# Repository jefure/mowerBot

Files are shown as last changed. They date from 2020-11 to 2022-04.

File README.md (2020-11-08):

# mowerBot
Code for a lawn mowing robot using python on a raspberry py and an arduino

References:
https://howtomechatronics.com/tutorials/arduino/arduino-dc-motor-control-tutorial-l298n-pwm-h-bridge/

Simular Projects:
https://www.ardumower.de/en/
https://github.com/sm6yvr/liam
https://github.com/trycoon/liam-esp

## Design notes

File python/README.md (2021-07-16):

# Raspberry Pi code for controlling the mower bot.

In this folder you'll find the code that should be installed on the raspberry pi to controll the bot.

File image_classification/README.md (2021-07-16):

# How to train the model

## Introduction
This guide provides instructions how to train a tensorflow image classification model and to convert it to tflie so that it can be used on a Raspberry Pi.

You are supposed to do the training a your desktop.

## Contents
1. [Docker](#docker)
2. [VirtualEnv](#python-venv)

## Docker
You can use the prebuild tensorflow jupyter docker environment from https://hub.docker.com/r/jupyter/tensorflow-notebook.

To use the docker image execute this steps:
This has been tested on Ubuntu 20.04

1.  A computer with an NVIDIA GPU is required.
2.  Verify that the driver from NVIDIA is used 
3.  Install [Docker](https://get.docker.com/) version **1.10.0+**
 and [Docker Compose](https://docs.docker.com/compose/install/) version **1.6.0+**.
4.  Get access to your GPU via CUDA drivers within Docker containers.
    You can be sure that you can access your GPU within Docker, 
    if the command `docker run --gpus all nvidia/cuda:10.1-cudnn7-runtime-ubuntu18.04 nvidia-smi`
    returns a result similar to this one:
    ```bash
    Tue Jan  5 09:38:21 2021       
    +-----------------------------------------------------------------------------+
    | NVIDIA-SMI 450.80.02    Driver Version: 450.80.02    CUDA Version: 10.1     |
    |-------------------------------+----------------------+----------------------+
    | GPU  Name        Persistence-M| Bus-Id        Disp.A | Volatile Uncorr. ECC |
    | Fan  Temp  Perf  Pwr:Usage/Cap|         Memory-Usage | GPU-Util  Compute M. |
    |                               |                      |               MIG M. |
    |===============================+======================+======================|
    |   0  GeForce RTX 207...  Off  | 00000000:01:00.0  On |                  N/A |
    |  0%   40C    P8     7W / 215W |    360MiB /  7974MiB |      1%      Default |
    |                               |                      |                  N/A |
    +-------------------------------+----------------------+----------------------+
                                                                                   
    +-----------------------------------------------------------------------------+
    | Processes:                                                                  |
    |  GPU   GI   CI        PID   Type   Process name                  GPU Memory |
    |        ID   ID                                                   Usage      |
    |=============================================================================|
    +-----------------------------------------------------------------------------+
    ``` 
    If you don't get an output similar than this one, follow the installation steps in this 
[medium article](https://medium.com/@christoph.schranz/set-up-your-own-gpu-based-jupyterlab-e0d45fcacf43).
    The CUDA toolkit is not required on the host system, as it will be 
    installed within the Docker containers using [NVIDIA-docker](https://github.com/NVIDIA/nvidia-docker).
    It is also important to keep your installed CUDA version in mind, when you pull images. 
    **You can't run images based on `nvidia/cuda:11.1` if you have only CUDA version 10.1 installed.**
    Check your host's CUDA-version with `nvcc --version` and update to at least 
    the same version you want to pull.
    
4. Pull and run the image. This can last some hours, as a whole data-science 
    environment will be downloaded:
   ```bash
   docker run --gpus all -d -it -p 8848:8888 -v $(pwd)/data:/home/jovyan/work -e GRANT_SUDO=yes -e JUPYTER_ENABLE_LAB=yes --user root cschranz/gpu-jupyter:v1.3_cuda-10.1_ubuntu-18.04_python-only
   ```
   This starts an instance with of *GPU-Jupyter* the tag `v1.3_cuda-10.1_ubuntu-18.04_python-only` at [http://localhost:8848](http://localhost:8848) (port `8484`).
   The default password is `gpu-jupyter` which should be changed as described [below](#set-password). 
   Furthermore, data within the host's `data` directory is shared with the container.
   Other versions of GPU-Jupyter are available and listed on Dockerhub under  [Tags](https://hub.docker.com/r/cschranz/gpu-jupyter/tags?page=1&ordering=last_updated).
   
5. Open the file TrainMowerModel.ipynb and run the content to train a new model

Within the Jupyterlab instance, you can check if you can access your GPU by opening a new terminal window and running
`nvidia-smi`. In terminal windows, you can also install new packages for your own projects. 
Some example code can be found in the repository under `extra/Getting_Started`.
If you want to learn more about Jupyterlab, check out this [tutorial](https://www.youtube.com/watch?v=7wfPqAyYADY).

Or use a [Google Tensorflow container](https://hub.docker.com/r/tensorflow/tensorflow/) 

## VirtualEnv

You can also use a Python virtual environment to run a script that trains a model

1. Python3 venv must be installed. If not run 'sudo apt install python3-venv'
2. Create a new virtual environment python3 -m venv ./training (See https://docs.python.org/3/library/venv.html)
3. Activate the venv source training/bin/activate
4. Install the requirements
	pip install --upgrade pip
	pip install tensorflow
	pip install opencv-python
	
	If you want local GPU Support see [GPU support](https://www.tensorflow.org/install/gpu?hl=de)
5. Run 'train.py' to create a tflite model
6. Test the model by running the 'detect_in_video.py' script

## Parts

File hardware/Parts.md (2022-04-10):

# Teileliste

2 x DN High Torque 12V DC 30 RPM Getriebe Elektromotor Ersatz 5000r / min https://www.amazon.de/gp/product/B00EQ1X04C/ref=ppx_yo_dt_b_asin_title_o01_s00?ie=UTF8&psc=1
2 x TOOGOO 37mm DC Getriebemotor Montagehalterung Halter + 6 mm Hex Kupplung Schwarz + Golden https://www.amazon.de/gp/product/B01EYDB6L0/ref=ppx_yo_dt_b_asin_title_o03_s00?ie=UTF8&psc=1
1 x Neuftech L298N Dual H-Brücke DC Stepper Motortreiber https://www.amazon.de/gp/product/B01KBTNHS6/ref=ppx_yo_dt_b_asin_title_o05_s00?ie=UTF8&psc=1
1 x Starre Flanschkupplung, 3 mm Innendurchmesser, H13 x D10 https://www.amazon.de/gp/product/B08MZ4XFL1/ref=ppx_yo_dt_b_asin_title_o09_s00?ie=UTF8&psc=1
1 x Gleichstrom-Kohlebürstenmotor 6V 4000 U/min https://www.amazon.de/gp/product/B07WRZNHNN/ref=ppx_yo_dt_b_asin_title_o01_s00?ie=UTF8&psc=1
1 x 3 x 1-Relais 5V KY-019 Modul High-Level-Trigger kompatibel mit Arduino  https://www.amazon.de/gp/product/B07CNR7K9B/ref=ppx_yo_dt_b_asin_title_o03_s00?ie=UTF8&psc=1
1 x Arduino Uno
1 x Raspberry Pi 3B
1 x Raspberry Pi Camera
1 x UBEC 5v 3A

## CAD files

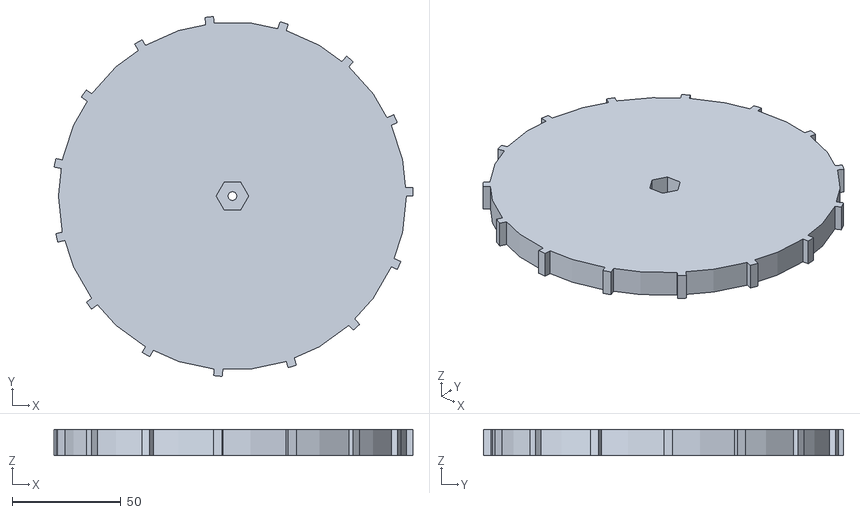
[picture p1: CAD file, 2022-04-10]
hardware/MaeherVorderrad.stl
165.0 x 165.5 x 12.0

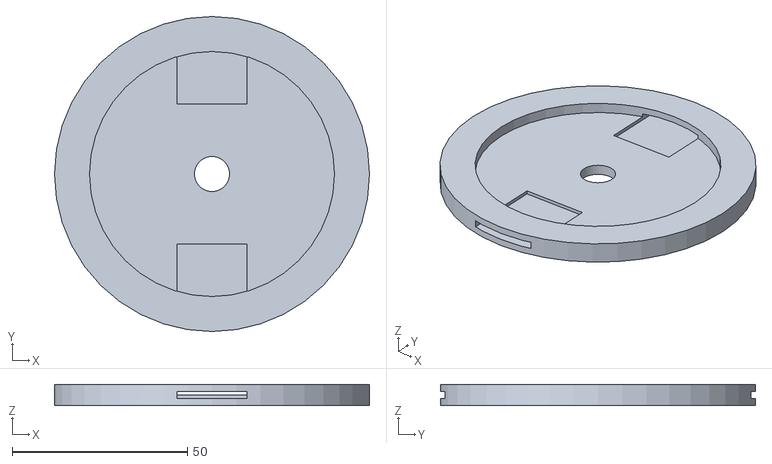
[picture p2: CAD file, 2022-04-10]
hardware/MaeherScheibe.stl
90.0 x 90.0 x 6.00

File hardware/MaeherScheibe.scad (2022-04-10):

$fn = 40;
outer_radius = 45;
inner_diameter = 10;
thickness = 4;
blade_length = 60;
blade_width = 20;
blade_thickness = 2;

difference() {
    cylinder(h = thickness + 2, r = outer_radius);
    translate([0,0,thickness -1])
        cylinder(h = 6, r = outer_radius - 10);
    cylinder(h = thickness + 2, d = inner_diameter);
    translate([- (blade_width / 2), blade_length / 3, 2]) cube(size = [blade_width, blade_length, blade_thickness]);
    translate([- (blade_width / 2), - (blade_length + (blade_length / 3)), 2]) cube(size = [blade_width, blade_length, blade_thickness]);
}

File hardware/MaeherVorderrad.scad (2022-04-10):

$fs = 0.01;
wheel_radius = 80;

module wheel() {
    thickness = 12;
    
    difference() {
        cylinder(h=thickness,r=wheel_radius);
        translate([0,0,-2])  cylinder(h=14, r=2);
    }
}

difference() {
    wheel();
    translate([0,0,2]) hexagon(indiameter=13);    
}

function indiameter_to_diameter(d) = d/(sqrt(3)/2);
module hexagon(indiameter, height = 12){
    diameter = indiameter_to_diameter(indiameter);
    translate([0,0,0])  cylinder(d=diameter, h = height + 4, $fn=6);
};
module tooth() {
    cube([4, 4, 12]);
}

for(i=[0:15]) //n is number of teeth
    rotate([0,0,i*360/15])
        translate([wheel_radius - 1,0,0]) // r is radius of circle
            tooth();

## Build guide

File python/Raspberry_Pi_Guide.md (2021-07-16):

# Part 2 - How to Run TensorFlow Lite Object Detection Models on the Raspberry Pi (with Optional Coral USB Accelerator)

This is a copy from [Section 2. Run Edge TPU Object Detection Models on the Raspberry Pi Using the Coral USB Accelerator](https://github.com/EdjeElectronics/TensorFlow-Lite-Object-Detection-on-Android-and-Raspberry-Pi/blob/master/Raspberry_Pi_Guide.md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) by EdjeElectronics

<p align="center">
   
</p>

## Introduction
This guide provides step-by-step instructions for how to set up TensorFlow Lite on the Raspberry Pi and use it to run object detection models. It also shows how to set up the Coral USB Accelerator on the Pi and run Edge TPU detection models. It works for the Raspberry Pi 3 and Raspberry Pi 4 running either Rasbpian Buster or Rasbpian Stretch.

This guide is the second part of my larger TensorFlow Lite tutorial series:

1. [How to Train, Convert, and Run Custom TensorFlow Lite Object Detection Models on Windows 10](https://github.com/EdjeElectronics/TensorFlow-Lite-Object-Detection-on-Android-and-Raspberry-Pi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)
2. How to Run TensorFlow Lite Object Detection Models on the Raspberry Pi (with Optional Coral USB Accelerator) *<--- You are here!*
3. How to Run TensorFlow Lite Object Detection Models on Android Devices

TensorFlow Lite (TFLite) models run much faster than regular TensorFlow models on the Raspberry Pi. You can see a comparison of framerates obtained using regular TensorFlow, TensorFlow Lite, and Coral USB Accelerator models in my [TensorFlow Lite Performance Comparison YouTube video](https://www.youtube.com/watch?v=TiOKvOrYNII).

This portion of the guide is split in to three sections:

* [Section 1. Run TensorFlow Lite Object Detection Models on the Raspberry Pi](https://github.com/EdjeElectronics/TensorFlow-Lite-Object-Detection-on-Android-and-Raspberry-Pi/blob/master/Raspberry_Pi_Guide.md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)
* [Section 2. Run Edge TPU Object Detection Models on the Raspberry Pi Using the Coral USB Accelerator](https://github.com/EdjeElectronics/TensorFlow-Lite-Object-Detection-on-Android-and-Raspberry-Pi/blob/master/Raspberry_Pi_Guide.md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)
* [Section 3. Compile Custom Edge TPU Object Detection Models](https://github.com/EdjeElectronics/TensorFlow-Lite-Object-Detection-on-Android-and-Raspberry-Pi/blob/master/Raspberry_Pi_Guide.md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)

This repository also includes scripts for running the TFLite and Edge TPU models on images, videos, or webcam/Picamera feeds.

## Section 1 - How to Set Up and Run TensorFlow Lite Object Detection Models on the Raspberry Pi

Setting up TensorFlow Lite on the Raspberry Pi is much easier than regular TensorFlow! These are the steps needed to set up TensorFlow Lite:

- 1a. Update the Raspberry Pi
- 1b. Download this repository and create virtual environment
- 1c. Install TensorFlow and OpenCV
- 1d. Set up TensorFlow Lite detection model
- 1e. Run TensorFlow Lite model!

I also made a YouTube video that walks through this guide:

Link to my YouTube video! (https://www.youtube.com/watch?v=aimSGOAUI8Y)

### Step 1a. Update the Raspberry Pi
First, the Raspberry Pi needs to be fully updated. Open a terminal and issue:
```
sudo apt-get update
sudo apt-get dist-upgrade
```
Depending on how long it’s been since you’ve updated your Pi, the update could take anywhere between a minute and an hour. 

While we're at it, let's make sure the camera interface is enabled in the Raspberry Pi Configuration menu. Click the Pi icon in the top left corner of the screen, select Preferences -> Raspberry Pi Configuration, and go to the Interfaces tab and verify Camera is set to Enabled. If it isn't, enable it now, and reboot the Raspberry Pi.

<p align="center">
  
</p>

### Step 1b. Download this repository and create virtual environment

Next, clone this GitHub repository by issuing the following command. The repository contains the scripts we'll use to run TensorFlow Lite, as well as a shell script that will make installing everything easier. Issue:

```
git clone https://github.com/EdjeElectronics/TensorFlow-Lite-Object-Detection-on-Android-and-Raspberry-Pi.git
```

This downloads everything into a folder called TensorFlow-Lite-Object-Detection-on-Android-and-Raspberry-Pi. That's a little long to work with, so rename the folder to "tflite1" and then cd into it:

```
mv TensorFlow-Lite-Object-Detection-on-Android-and-Raspberry-Pi tflite1
cd tflite1
```

We'll work in this /home/pi/tflite1 directory for the rest of the guide. Next up is to create a virtual environment called "tflite1-env".

I'm using a virtual environment for this guide because it prevents any conflicts between versions of package libraries that may already be installed on your Pi. Keeping TensorFlow installed in its own environment allows us to avoid version conflicts. For example, if you've already installed TensorFlow v1.8 on the Pi using my [other guide](https://www.youtube.com/watch?v=npZ-8Nj1YwY), you can leave that installation as-is without having to worry about overriding it.

Install virtualenv by issuing:

```
sudo pip3 install virtualenv
```

Then, create the "tflite1-env" virtual environment by issuing:

```
python3 -m venv tflite1-env
```

This will create a folder called tflite1-env inside the tflite1 directory. The tflite1-env folder will hold all the package libraries for this environment. Next, activate the environment by issuing:

```
source tflite1-env/bin/activate
```

**You'll need to issue the `source tflite1-env/bin/activate` command from inside the /home/pi/tflite1 directory to reactivate the environment every time you open a new terminal window. You can tell when the environment is active by checking if (tflite1-env) appears before the path in your command prompt, as shown in the screenshot below.**

At this point, here's what your tflite1 directory should look like if you issue `ls`.

<p align="center">
  
</p>

If your directory looks good, it's time to move on to Step 1c!

### Step 1c. Install TensorFlow Lite dependencies and OpenCV
Next, we'll install TensorFlow, OpenCV, and all the dependencies needed for both packages. OpenCV is not needed to run TensorFlow Lite, but the object detection scripts in this repository use it to grab images and draw detection results on them.

To make things easier, I wrote a shell script that will automatically download and install all the packages and dependencies. Run it by issuing:

```
bash get_pi_requirements.sh
```

This downloads about 400MB worth of installation files, so it will take a while. Go grab a cup of coffee while it's working! If you'd like to see everything that gets installed, simply open get_pi_dependencies.sh to view the list of packages.

**NOTE: If you get an error while running the `bash get_pi_requirements.sh` command, it's likely because your internet connection timed out, or because the downloaded package data was corrupted. If you get an error, try re-running the command a few more times.**

**ANOTHER NOTE: The shell script automatically installs the latest version of TensorFlow. If you'd like to install a specific version, issue `pip3 install tensorflow==X.XX` (where X.XX is replaced with the version you want to install) after running the script. This will override the existing installation with the specified version.**

That was easy! On to the next step.

### Step 1d. Set up TensorFlow Lite detection model
Next, we'll set up the detection model that will be used with TensorFlow Lite. This guide shows how to either download a sample TFLite model provided by Google, or how to use a model that you've trained yourself by following [Part 1 of my TensorFlow Lite tutorial series](https://github.com/EdjeElectronics/TensorFlow-Lite-Object-Detection-on-Android-and-Raspberry-Pi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).

A detection model has two files associated with it: a detect.tflite file (which is the model itself) and a labelmap.txt file (which provides a labelmap for the model). My preferred way to organize the model files is to create a folder (such as "BirdSquirrelRaccoon_TFLite_model") and keep both the detect.tflite and labelmap.txt in that folder. This is also how Google's downloadable sample TFLite model is organized.

#### Option 1. Using Google's sample TFLite model
Google provides a sample quantized SSDLite-MobileNet-v2 object detection model which is trained off the MSCOCO dataset and converted to run on TensorFlow Lite. It can detect and identify 80 different common objects, such as people, cars, cups, etc.

Download the sample model (which can be found on [the Object Detection page of the official TensorFlow website](https://www.tensorflow.org/lite/models/object_detection/overview)) by issuing:

```
wget https://storage.googleapis.com/download.tensorflow.org/models/tflite/coco_ssd_mobilenet_v1_1.0_quant_2018_06_29.zip
```

Unzip it to a folder called "Sample_TFLite_model" by issuing (this command automatically creates the folder):

```
unzip coco_ssd_mobilenet_v1_1.0_quant_2018_06_29.zip -d Sample_TFLite_model
```

Okay, the sample model is all ready to go! 

#### Option 2: Using your own custom-trained model
You can also use a custom object detection model by moving the model folder into the /home/pi/tflite directory. If you followed [Part 1 of my TensorFlow Lite guide](https://github.com/EdjeElectronics/TensorFlow-Lite-Object-Detection-on-Android-and-Raspberry-Pi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) to train and convert a TFLite model on your PC, you should have a folder named "TFLite_model" with a detect.tflite and labelmap.txt file. (It will also have a tflite_graph.pb and tflite_graph.pbtxt file, which are not needed by TensorFlow Lite but can be left in the folder.) 

You can simply copy that folder to a USB drive, insert the USB drive in your Raspberry Pi, and move the folder into the /home/pi/tflite1 directory. (Or you can email it to yourself, or put it on Google Drive, or do whatever your preferred method of file transfer is.) Here's an example of what my "BirdSquirrelRaccoon_TFLite_model" folder looks like in my /home/pi/tflite1 directory: 

<p align="center">
  
</p>

Now your custom model is ready to go!

### Step 1e. Run the TensorFlow Lite model!
It's time to see the TFLite object detection model in action! First, free up memory and processing power by closing any applications you aren't using. Also, make sure you have your webcam or Picamera plugged in.

Run the real-time webcam detection script by issuing the following command from inside the /home/pi/tflite1 directory. (Before running the command, make sure the tflite1-env environment is active by checking that (tflite1-env) appears in front of the command prompt.) **The TFLite_detection_webcam.py script will work with either a Picamera or a USB webcam.**

```
python3 TFLite_detection_webcam.py --modeldir=Sample_TFLite_model
```

If your model folder has a different name than "Sample_TFLite_model", use that name instead. For example, I would use `--modeldir=BirdSquirrelRaccoon_TFLite_model` to run my custom bird, squirrel, and raccoon detection model.

After a few moments of initializing, a window will appear showing the webcam feed. Detected objects will have bounding boxes and labels displayed on them in real time.

Part 3 of my TensorFlow Lite training guide gives [instructions](https://github.com/EdjeElectronics/TensorFlow-Lite-Object-Detection-on-Android-and-Raspberry-Pi#video) for using the TFLite_detection_image.py and TFLite_detection_video.py scripts. Make sure to use `python3` rather than `python` when running the scripts.

## Section 2 - Run Edge TPU Object Detection Models on the Raspberry Pi Using the Coral USB Accelerator

Link to Section 2 YouTube video! (https://www.youtube.com/watch?v=qJMwNHQNOVU)

The [Coral USB Accelerator](https://coral.withgoogle.com/products/accelerator/) is a USB hardware accessory for speeding up TensorFlow models. You can buy one [here (Amazon Associate link)](https://amzn.to/2BuG1Tv). 

The USB Accelerator uses the Edge TPU (tensor processing unit), which is an ASIC (application-specific integrated circuit) chip specially designed with highly parallelized ALUs (arithmetic logic units). While GPUs (graphics processing units) also have many parallelized ALUs, the TPU has one key difference: the ALUs are directly connected to eachother. The output of one ALU can be directly passed to the input of the next ALU without having to be stored and retrieved from a memory buffer. The extreme paralellization and removal of the memory bottleneck means the TPU can perform up to 4 trillion arithmetic operations per second! This is perfect for running deep neural networks, which require millions of multiply-accumulate operations to generate outputs from a single batch of input data. 

<p align="center">
  
</p>

My Master's degree was in ASIC design, so the Edge TPU is very interesting to me! If you're a computer architecture nerd like me and want to learn more about the Edge TPU, [here is a great article that explains how it works](https://cloud.google.com/blog/products/ai-machine-learning/what-makes-tpus-fine-tuned-for-deep-learning).

It makes object detection models run WAY faster, and it's easy to set up. These are the steps we'll go through to set up the Coral USB Accelerator:

- 2a. Install libedgetpu library
- 2b. Set up Edge TPU detection model
- 2c. Run super-speed detection!

This section of the guide assumes you have already completed [Section 1](https://github.com/EdjeElectronics/TensorFlow-Lite-Object-Detection-on-Android-and-Raspberry-Pi/blob/master/Raspberry_Pi_Guide.md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) for setting up TFLite object detection on the Pi. If you haven't done that portion, scroll back up and work through it first.

### Step 2a. Install libedgetpu library
First, we'll download and install the Edge TPU runtime, which is the library needed to interface with the USB Acccelerator. These instructions follow the [USB Accelerator setup guide](https://coral.withgoogle.com/docs/accelerator/get-started/) from official Coral website.

Open a command terminal and move into the /home/pi/tflite1 directory and activate the tflite1-env virtual environment by issuing:

```
cd /home/pi/tflite1
source tflite1-env/bin/activate
```

Add the Coral package repository to your apt-get distribution list by issuing the following commands:

```
echo "deb https://packages.cloud.google.com/apt coral-edgetpu-stable main" | sudo tee /etc/apt/sources.list.d/coral-edgetpu.list
curl https://packages.cloud.google.com/apt/doc/apt-key.gpg | sudo apt-key add -
sudo apt-get update
```

Install the libedgetpu library by issuing:

```
sudo apt-get install libedgetpu1-std
```

You can also install the libedgetpu1-max library, which runs the USB Accelerator at an overclocked frequency, allowing it to achieve even faster framerates. However, it also causes the USB Accelerator to get hotter. Here are the framerates I get when running TFLite_detection_webcam.py with 1280x720 resolution for each option with a Raspberry Pi 4 4GB model:

* libedgetpu1-std: 22.6 FPS
* libedgetpu1-max: 26.1 FPS

I didn't measure the temperature of the USB Accelerator, but it does get a little hotter to the touch with the libedgetpu1-max version. However, it didn't seem hot enough to be unsafe or harmful to the electronics.

If you want to use the libedgetpu-max library, install it by using `sudo apt-get install libedgetpu1-max`. (You can't have both the -std and the -max libraries installed. If you install the -max library, the -std library will automatically be uninstalled.)

Alright! Now that the libedgetpu runtime is installed, it's time to set up an Edge TPU detection model to use it with.

### Step 2b. Set up Edge TPU detection model
Edge TPU models are TensorFlow Lite models that have been compiled specifically to run on Edge TPU devices like the Coral USB Accelerator. They reside in a .tflite file and are used the same way as a regular TF Lite model. My preferred method is to keep the Edge TPU file in the same model folder as the TFLite model it was compiled from, and name it as "edgetpu.tflite".

I'll show two options for setting up an Edge TPU model: using the sample model from Google, or using a custom model you compiled yourself.

#### Option 1. Using Google's sample EdgeTPU model
Google provides a sample Edge TPU model that is compiled from the quantized SSDLite-MobileNet-v2 we used in [Step 1e](https://github.com/EdjeElectronics/TensorFlow-Lite-Object-Detection-on-Android-and-Raspberry-Pi/blob/master/Raspberry_Pi_Guide.md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). Download it and move it into the Sample_TFLite_model folder (while simultaneously renaming it to "edgetpu.tflite") by issuing these commands:

```
wget https://dl.google.com/coral/canned_models/mobilenet_ssd_v2_coco_quant_postprocess_edgetpu.tflite

mv mobilenet_ssd_v2_coco_quant_postprocess_edgetpu.tflite Sample_TFLite_model/edgetpu.tflite
```

Now the sample Edge TPU model is all ready to go. It will use the same labelmap.txt file as the TFLite model, which should already be located in the Sample_TFLite_model folder.

#### Option 2. Using your own custom EdgeTPU model
If you trained a custom TFLite detection model, you can compile it for use with the Edge TPU. Unfortunately, the edgetpu-compiler package doesn't work on the Raspberry Pi: you need a Linux PC to use it on. Section 3 of this guide will give a couple options for compiling your own model if you don't have a Linux box. While I'm working on writing it, [here are the official instructions that show how to compile an Edge TPU model from a TFLite model](https://coral.withgoogle.com/docs/edgetpu/compiler/).

Assuming you've been able to compile your TFLite model into an EdgeTPU model, you can simply copy the .tflite file onto a USB and transfer it to the model folder on your Raspberry Pi. For my "BirdSquirrelRaccoon_TFLite_model" example from [Step 1e](https://github.com/EdjeElectronics/TensorFlow-Lite-Object-Detection-on-Android-and-Raspberry-Pi/blob/master/Raspberry_Pi_Guide.md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), I can compile my "BirdSquirrelRaccoon_TFLite_model" on a Linux PC, put the resulting edgetpu.tflite file on a USB, transfer the USB to my Pi, and move the edgetpu.tflite file into the /home/pi/tflite1/BirdSquirrelRaccoon_TFLite_model folder. It will use the same labelmap.txt file that already exists in the folder to get its labels.

Once the edgetpu.tflite file has been moved into the model folder, it's ready to go!

### Step 2c. Run detection with Edge TPU!

Now that everything is set up, it's time to test out the Coral's ultra-fast detection speed! Make sure to free up memory and processing power by closing any programs you aren't using. Make sure you have a webcam plugged in.

Plug in your Coral USB Accelerator into one of the USB ports on the Raspberry Pi. If you're using a Pi 4, make sure to plug it in to one of the blue USB 3.0 ports.

*Insert picture of Coral USB Accelerator plugged into Raspberry Pi here!*

Make sure the tflite1-env environment is activate by checking that (tflite1-env) appears in front of the command prompt in your terminal. Then, run the real-time webcam detection script with the --edgetpu argument:

```
python3 TFLite_detection_webcam.py --modeldir=Sample_TFLite_model --edgetpu
```

The `--edgetpu` argument tells the script to use the Coral USB Accelerator and the EdgeTPU-compiled .tflite file. If your model folder has a different name than "Sample_TFLite_model", use that name instead.

After a brief initialization period, a window will appear showing the webcam feed with detections drawn on each from. The detection will run SIGNIFICANTLY faster with the Coral USB Accelerator.

If you'd like to run the video or image detection scripts with the Accelerator, use these commands:

```
python3 TFLite_detection_video.py --modeldir=Sample_TFLite_model --edgetpu
python3 TFLite_detection_image.py --modeldir=Sample_TFLite_model --edgetpu
```

Have fun with the blazing detection speeds of the Coral USB Accelerator!

## Section 3 - Compile Custom Edge TPU Object Detection Models

To use a custom model on the Coral USB Accelerator, you have to run it through Coral's [Edge TPU Compiler](https://coral.ai/docs/edgetpu/compiler/) tool. Unfortunately, the compiler only works on Linux operating systems, and only on certain CPU architectures. 

The easiest way to compile the Edge TPU model is to use a Google Colab session. I created a Colab page specifically for compiling Edge TPU models. Please click the link below and follow the instructions in the Colab notebook.

https://colab.research.google.com/drive/1o6cNNNgGhoT7_DR4jhpMKpq3mZZ6Of4N?usp=sharing

## Appendix: Common Errors
This appendix lists common errors that have been encountered by users following this guide, and solutions showing how to resolve them.

**Feel free to create Pull Requests to add your own errors and resolutions! I'd appreciate any help.**

### 1. TypeError: int() argument must be a string, a bytes-like object or a number, not 'NoneType'
The 'NoneType' error means that the program received an empty array from the webcam, which typically means something is wrong with the webcam or the interface to the webcam. Try plugging and re-plugging the webcam in a few times, and/or power cycling the Raspberry Pi, and see if that works. If not, you may need to try using a new webcam.

### 2. ImportError: No module named 'cv2'
This error occurs when you try to run any of the TFLite_detection scripts without activating the 'tflite1-env' first. It happens because Python cannot find the path to the OpenCV library (cv2) to import it. 

Resolve the issue by closing your terminal window, re-opening it, and issuing:

```
cd tflite1
source tflite1-env/bin/activate
```

Then, try re-running the script as described in [Step 1e](https://github.com/EdjeElectronics/TensorFlow-Lite-Object-Detection-on-Android-and-Raspberry-Pi/blob/master/Raspberry_Pi_Guide.md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).

### 3. THESE PACKAGES DO NOT MATCH THE HASHES FROM THE REQUIREMENTS FILE
This error can occur when you run the `bash get_pi_requirements.sh` command in Step 1c. It occurs because the package data got corrupted while downloading. You can resolve the error by re-running the `bash get_pi_requirements.sh` command a few more times until it successfully completes without reporting that error.

### 4. Unsupported data type in custom op handler: 6488064Node number 2 (EdgeTpuDelegateForCustomOp) failed to prepare.
This error occurs when trying to use a newer version of the libedgetpu library (v13.0 or greater) with an older version of TensorFlow (v2.0 or older). It can be resolved by uninstalling your current version of TensorFlow and installing the latest version of the tflite_runtime package. Issue these commands (make sure you are inside the tflite1-env virtual environment):

```
pip3 uninstall tensorflow
pip3 install https://dl.google.com/coral/python/tflite_runtime-2.1.0.post1-cp37-cp37m-linux_armv7l.whl
```

(Or, if you're using Python 3.5, use `pip3 install https://dl.google.com/coral/python/tflite_runtime-2.1.0.post1-cp35-cp35m-linux_armv7l.whl` instead.)

Then, re-run the TFLite detection script. It should work now!

*Note: the URLs provided in these commands may change as newer versions of tflite_runtime are released. Check the [TFLite Python Quickstart page](https://www.tensorflow.org/lite/guide/python) for download URLs to the latest version of tflite_runtime.*

### 5. IndexError: list index out of range
This error usually occurs when you try using an "image classification" model rather than an "object detection" model. Image classification models apply a single label to an image, while object detection models locate and label multiple objects in an image. The code in this repository is written for object detection models.

Many people run in to this error when using models from Teachable Machine. This is because Teachable Machine creates image classification models rather than object detection models. To create an object detection model for TensorFow Lite, you'll have to follow the guide in this repository.

If you'd like to see how to use an image classification model on the Raspberry Pi, please see this example:
https://github.com/tensorflow/examples/tree/master/lite/examples/image_classification/raspberry_pi

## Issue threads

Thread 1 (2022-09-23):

How to convert model-large.tflite to model.tflite

FireSon, 2022-09-23:
Hi I was trying out your solution with the image classification. And since I am new to the ML things I just followed all the steps in the juptyr notebook. After I finished all the steps it seemed that I got the same file as your model-large.ltlite and I was not able to get the model.lflite. Could you please help me understand how to create this file?
Probably there is some conversion taking place since the file is much smaller and also contains meta data. If I take the steps described to add meta data to the model my file stays about the same size and it does not seem to work quite as well on my android phone...
Cheers,
Jan

jefure, 2022-10-16:
Hi, Jan
sorry for may late reply. I've never tested the model on android. So I'm not able to help you there. May there is a problem with the tensor flow version. I'm using the generated models to run with tensorflow light on a rasberry pi. Maybe the tutorial from google https://www.tensorflow.org/lite/examples/image_classification/overview can help you. I also used two different methods to generate the models. The first one is the method using the jupyter note book. This method creates a larger more performant model. You find the saved model in mounted output folder of the jupyter docker container. The second method uses the tensorflow model maker as described here https://www.tensorflow.org/lite/api_docs/python/tflite_model_maker. It uses the train.py script to create a simpler but smaller model. I hope this information helps
Kind regards
Jens

FireSon, 2022-10-28:
Hi Jens,
No problem! In the end I solved it, although it was quite difficult since the versioning within python was quite sensitive. The model also works well on android. Do you still use your solution in real life? Does it work well?
Kind regards,
Jan

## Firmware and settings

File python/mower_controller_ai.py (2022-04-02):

#! /usr/bin/env python

#
# This file is part of the mowbit distribution (https://github.com/jefure/mowbot).
# Copyright (c) 2022 Jens Reese.
#
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

import time
import os
import io
import pygame
import serial
import sys
import struct
import numpy as np
import cv2
import importlib.util
import picamera
import argparse
import threading
import queue
from PIL import Image
import driver

driveMode = "manual"
job_queue = queue.Queue()
newClassificationResultAvailable = False
imageClassificationResult = []


class Job(object):
    def __init__(self, input):
        self.frame = input[1]
        self.interpreter = input[0]


def do_job(job):
    result = classify_image(job.interpreter, job.frame)


class Worker(threading.Thread):
    def run(self):
        while True:
            job = job_queue.get(block=True)

            do_job(job)


def set_input_tensor(interpreter, image):
    tensor_index = interpreter.get_input_details()[0]['index']
    input_tensor = interpreter.tensor(tensor_index)()[0]
    input_tensor[:, :] = image


def classify_image(interpreter, image, top_k=1):
    """Returns a sorted array of classification results."""
    global imageClassificationResult
    global newClassificationResultAvailable

    start_time = time.time()
    set_input_tensor(interpreter, image)
    interpreter.invoke()
    output_details = interpreter.get_output_details()[0]
    output = np.squeeze(interpreter.get_tensor(output_details['index']))

    # If the model is quantized (uint8 data), then dequantize the results
    if output_details['dtype'] == np.uint8:
        scale, zero_point = output_details['quantization']
        output = scale * (output - zero_point)

    ordered = np.argpartition(-output, top_k)
    elapsed_ms = (time.time() - start_time) * 1000
    imageClassificationResult = [[(i, output[i]) for i in ordered[:top_k]], elapsed_ms]
    newClassificationResultAvailable = True

    return imageClassificationResult


def process_result(results, do_save_images, labels, stream, preview, camera):
    label_id, prob = results[0][0]
    stream.seek(0)
    stream.truncate()


    if do_save_images:
        timestamp = time.time()
        if label_id == 1 and prob > 0.90:
            camera.capture(f'/home/pi/Pictures/good/mow_{timestamp}.jpg')
        else:
            camera.capture(f'/home/pi/Pictures/bad/mow_{timestamp}.jpg')

        if preview:
            camera.annotate_text = '%s %.2f\n%.1fms' % (labels[label_id], prob, results[1])
        else:
            print('%s %.2f\n%.1fms' % (labels[label_id], prob, results[1]))

        return label_id, prob


def main():
    global driveMode

    parser = argparse.ArgumentParser(formatter_class=argparse.ArgumentDefaultsHelpFormatter)
    parser.add_argument('--model',
                        help='File path of .tflite file. Default: /home/pi/mowerBot/image_classification/saved_model/model.tflite',
                        required=False, default='/home/pi/mowerBot/image_classification/saved_model/model.tflite')
    parser.add_argument('--labels',
                        help='File path of labels file. Default: /home/pi/mowerBot/image_classification/saved_model/labelmap.txt',
                        required=False, default='/home/pi/mowerBot/image_classification/saved_model/labelmap.txt')
    parser.add_argument('--dry_run', help='Simulate motor control.', required=False, default=False)
    parser.add_argument('--video',
                        help='MP4 Video file for simulation the camera, can only be used with --dry_run together',
                        required=False)
    parser.add_argument('--preview', help='Preview camera image', required=False, default=False)
    parser.add_argument('--drive_mode', help='Change the default drive mode', required=False, default='manual')
    parser.add_argument('--save_images', help='Save images of camera', required=False, default=False)
    parser.add_argument('--use_thread', help='Run the image classification in a seperate thread', default=False)
    args = parser.parse_args()

    os.environ["SDL_VIDEODRIVER"] = "dummy"  # Removes the need to have a GUI window
    pygame.init()
    arduino = serial.Serial('/dev/ttyACM0', 115200, timeout=.1)
    modelPath = os.path.join(args.model)
    labelPath = os.path.join(args.labels)

    driveMode = args.drive_mode

    print("Init tensorflow")
    pkg = importlib.util.find_spec('tflite_runtime')
    if pkg:
        from tflite_runtime.interpreter import Interpreter
    else:
        from tensorflow.lite.python.interpreter import Interpreter

    # Load the label map
    with open(labelPath, 'r') as f:
        labels = [line.strip() for line in f.readlines()]

    interpreter = Interpreter(modelPath)
    interpreter.allocate_tensors()
    _, height, width, _ = interpreter.get_input_details()[0]['shape']

    worker = Worker()
    worker.start()

    print("Waiting for joystick... (press CTRL+C to abort)")
    try:
        while True:
            try:
                pygame.joystick.init()
                # Attempt to setup the joystick
                if pygame.joystick.get_count() < 1:
                    print("No joystick found")
                    pygame.joystick.quit()
                    time.sleep(0.1)
                else:
                    # We have a joystick, attempt to initialise it!
                    joystick = pygame.joystick.Joystick(0)
                    break
            except pygame.error:
                pygame.joystick.quit()
                time.sleep(0.1)
    except KeyboardInterrupt:
        # CTRL+C exit, give up
        print("\nUser aborted")
        sys.exit()

    joystick.init()

    print("Joystick initialized")
    if not args.video:
        use_pi_camera(labels, width, height, interpreter, joystick, arduino, args)
    else:
        use_video(labels, args.video, args.dry_run, width, height, interpreter, joystick, arduino)


def use_pi_camera(labels, width, height, interpreter, joystick, arduino, args):
    global newClassificationResultAvailable
    global imageClassificationResult
    preview = args.preview
    is_dry_run = args.dry_run
    do_save_images = args.save_images
    use_thread = args.use_thread
    """Get live image from the pi camera and classify the image."""
    print("Use Pi Cam.", preview, labels, is_dry_run)
    label_id = 0
    prob = 0
    with picamera.PiCamera(resolution=(320, 240), framerate=7) as camera:
        if preview:
            camera.start_preview()

        try:
            stream = io.BytesIO()
            for _ in camera.capture_continuous(stream, format='jpeg', use_video_port=True):
                stream.seek(0)
                image = Image.open(stream).convert('RGB').resize((width, height), Image.ANTIALIAS)

                if use_thread:
                    job_queue.put(Job([interpreter, image]))
                    if newClassificationResultAvailable:
                        results = imageClassificationResult
                        newClassificationResultAvailable = False
                        label_id, prob = process_result(results, doSaveImages, labels, stream, preview, camera)
                else:
                    results = classify_image(interpreter, image)
                    label_id, prob = process_result(results, doSaveImages, labels, stream, preview, camera)

                state = get_state(joystick, label_id, prob)

                if state:
                    driver(state, arduino, is_dry_run)
        except KeyboardInterrupt:
            print("\nBye")
        finally:
            if preview:
                camera.stop_preview()


def use_video(labels, video_path, is_dry_run, width, height, interpreter, joystick, arduino):
    global newClassificationResultAvailable
    global imageClassificationResult
    """Test the code using a video file"""
    video = cv2.VideoCapture(video_path)
    imW = video.get(cv2.CAP_PROP_FRAME_WIDTH)
    imH = video.get(cv2.CAP_PROP_FRAME_HEIGHT)

    while (video.isOpened()):
        ret, frame = video.read()
        if not ret:
            print("End of video reached.")
            break
        frame_rgb = cv2.cvtColor(frame, cv2.COLOR_BGR2RGB)
        frame_resized = cv2.resize(frame_rgb, (width, height))

        # Retrieve detection results
        job_queue.put(Job([interpreter, frame_resized]))

        while newClassificationResultAvailable is False:
            time.sleep(0.001)

        label_id, prob = imageClassificationResult[0][0]
        label = '%s: %d%% Time: %.1fms' % (labels[label_id], prob * 100, imageClassificationResult[1])
        newClassificationResultAvailable = False

        font = cv2.FONT_HERSHEY_SIMPLEX
        bottomLeftCornerOfText = (10, 470)
        fontScale = 1
        fontColor = (255, 255, 255)
        lineType = 2
        cv2.putText(frame, label, bottomLeftCornerOfText, font, fontScale, fontColor, lineType)

        state = get_state(joystick, label_id, prob)
        if state:
            driver.drive(state, arduino, is_dry_run)

            # All the results have been drawn on the frame, so it's time to display it.
        cv2.imshow('Object detector', frame)

        # Press 'q' to quit
        if cv2.waitKey(1) == ord('q'):
            break

    # Clean up
    video.release()
    cv2.destroyAllWindows()


def get_state(joystick, label_id, probability):
    global driveMode
    state = {"command": "stop", "motors": {"left": 0, "right": 0}, "mower": {"speed": 0}, "updated": False,
             "running": True}
    had_event = False
    events = pygame.event.get()
    for event in events:
        if event.type == pygame.JOYBUTTONDOWN or event.type == pygame.JOYBUTTONUP:
            print(event)
            a_button = joystick.get_button(0)
            x_button = joystick.get_button(3)
            y_button = joystick.get_button(4)
            b_button = joystick.get_button(1)
            if a_button == 1:
                driveMode = "auto"
            elif x_button == 1:
                driveMode = "manual"
                state["command"] = "stop"
                state["motors"]["right"] = 0
                state["motors"]["left"] = 0

            print("Drive mode:", driveMode)

        if event.type == pygame.JOYAXISMOTION:
            # A joystick has been moved
            had_event = True

        if had_event and driveMode == "manual":
            up_down = -joystick.get_axis(1)
            left_right = -joystick.get_axis(2)
            if left_right < -0.05:
                state["motors"]["left"] = 255 * left_right
            elif left_right > 0.05:
                state["motors"]["right"] = 255 * left_right
            else:
                state["motors"]["right"] = 255 * up_down
                state["motors"]["left"] = 255 * up_down

            if up_down < -0.05:
                state["command"] = "back"
            elif up_down > 0.05:
                state["command"] = "forward"
            else:
                state["command"] = "stop"
                state["motors"]["right"] = 0
                state["motors"]["left"] = 0

            state["motors"]["right"] = int(state["motors"]["right"])
            state["motors"]["left"] = int(state["motors"]["left"])

            if state["motors"]["right"] < 0:
                state["motors"]["right"] = state["motors"]["right"] * -1

            if state["motors"]["left"] < 0:
                state["motors"]["left"] = state["motors"]["left"] * -1

            state["updated"] = True
            return state

    if driveMode == "auto":
        if label_id == 1 and probability >= 0.9:
            state["command"] = "forward"
            state["motors"]["right"] = 255
            state["motors"]["left"] = 255
        elif label_id == 1 and probability < 0.9 and probability > 0.8:
            state["command"] = "forward"
            state["motors"]["right"] = 150
            state["motors"]["left"] = 150
        elif label_id == 2:
            state["command"] = "back"
            state["motors"]["right"] = 150
            state["motors"]["left"] = 150
        else:
            state["command"] = "stop"
            state["motors"]["right"] = 0
            state["motors"]["left"] = 0

        state["updated"] = True
        return state


if __name__ == '__main__':
    main()

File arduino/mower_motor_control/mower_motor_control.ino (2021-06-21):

const short MOTOR1 = 10;
const short IN1 = 8;
const short IN2 = 9;
const short MOTOR2 = 11;
const short IN3 = 13;
const short IN4 = 12;
const short MOTOR3 = 5;
// used for older arduino ide versions
const short LED_BUILDIN = 13;
byte incoming[4];

void setup() {
  //  enable serial
  Serial.begin(115200);
  pinMode(LED_BUILTIN, OUTPUT);
  // init moto pins
  pinMode(MOTOR1, OUTPUT);
  pinMode(MOTOR2, OUTPUT);
  pinMode(MOTOR3, OUTPUT); 
  pinMode(IN1, OUTPUT);
  pinMode(IN2, OUTPUT);
  pinMode(IN3, OUTPUT);
  pinMode(IN4, OUTPUT);
}

void loop() {  
  if(Serial.available() >= 4) {
      for (int i = 0; i < 4; i++) {
        incoming[i] = Serial.read();
      }      
  }

  runMotors(incoming[0], incoming[1], incoming[2], incoming[3]);
}

void runMotors(byte leftPower, byte rightPower, byte dir, byte mowerPower) {
  if (dir == 1) {
    digitalWrite(IN1, HIGH);
    digitalWrite(IN2, LOW);  
    digitalWrite(IN3, HIGH);
    digitalWrite(IN4, LOW);
  } else if (dir == 2) {
    digitalWrite(IN1, LOW);
    digitalWrite(IN2, HIGH);  
    digitalWrite(IN3, LOW);
    digitalWrite(IN4, HIGH);
  }

  if (mowerPower >= 129) {
    runMower();
  } else {
    stopMower();
  }

  analogWrite(MOTOR1, leftPower);
  analogWrite(MOTOR2, rightPower);
}

void stopMotors() {  
  digitalWrite(IN1, LOW);
  digitalWrite(IN2, LOW);
  digitalWrite(IN3, LOW);
  digitalWrite(IN4, LOW);
  analogWrite(MOTOR1, 0);
  analogWrite(MOTOR2, 0);
  stopMower();
}

void runMower() {
  digitalWrite(MOTOR3, HIGH);
}

void stopMower() {
  digitalWrite(MOTOR3, LOW);
}

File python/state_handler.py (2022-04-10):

#
# This file is part of the mowbot distribution (https://github.com/jefure/mowbot).
# Copyright (c) 2022 Jens Reese.
#
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
import pygame

vel = 0.5

def get_state(state, keys, sensor_data):
    state["updated"] = False
    
    if is_manual_mode(keys, state):
        state = manual_state(state, keys)
    else:
        state = automatic_state(state, sensor_data)        

    state["motors"]["right"] = int(state["motors"]["right"])
    state["motors"]["left"] = int(state["motors"]["left"])
    
    state["mower"]["speed"] = get_mower_speed(sensor_data, state["command"])

    state["updated"] = True
    return state


def automatic_state(state, sensor_data):
    state["manual"] = False
    if sensor_data["distance"] >= 45:
        state["command"] = "forward"
        state["motors"]["right"] = 255 * vel
        state["motors"]["left"] = 255 * vel
    elif sensor_data["distance"] < 45 and sensor_data["distance"] > 10:
        state["command"] = "forward"
        state["motors"]["right"] = 255 * vel
    elif sensor_data["distance"] < 10:
        state["command"] = "forward"
        state["motors"]["right"] = 0 * vel
        state["motors"]["left"] = 0 * vel
        
    return state


def manual_state(state, keys):
    state["manual"] = True
    state["command"] = "stop"
    state["motors"]["right"] = 0
    state["motors"]["left"] = 0
        
    if keys[pygame.K_RIGHT] == 1:
        state["command"] = "forward"
        state["motors"]["right"] = 255 * vel
    elif keys[pygame.K_LEFT] == 1:
        state["command"] = "forward"
        state["motors"]["left"] = 255 * vel
    elif keys[pygame.K_UP] == 1:
        state["command"] = "forward"
        state["motors"]["right"] = 255 * vel
        state["motors"]["left"] = 255 * vel
    elif keys[pygame.K_DOWN] == 1:
        state["command"] = "back"
        state["motors"]["right"] = 255 * vel
        state["motors"]["left"] = 255 * vel
        
    return state


def get_mower_speed(sensor_data, command):
    if command == "forward":
        print(command, " Data: ", sensor_data)
        if sensor_data["roll"] > 345 or sensor_data["roll"] < 5:
            if sensor_data["pitch"] > 10 or sensor_data["pitch"] < 345:
                return 255
            
    return 0


def is_manual_mode(keys, state):
    if keys[pygame.K_a] == 1:
        return False
    elif keys[pygame.K_m] == 1:
        return True
    
    return state["manual"]

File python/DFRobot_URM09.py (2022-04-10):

# -*- coding: utf-8 -*
'''!
  @file DFRobot_URM09.py
  @brief Define the basic structure of DFRobot_URM09 class, the implementation of basic method
  @copyright Copyright (c) 2010 DFRobot Co.Ltd (http://www.dfrobot.com)
  @license The MIT License (MIT)
  @author ZhixinLiu(zhixin.liu@dfrobot.com)
  @version V1.1
  @date 2021-9-30
  @url https://github.com/DFRobot/DFRobot_URM09
'''
import serial
import time
import smbus


class DFRobot_URM09(object):
    ## automatic mode
    _MEASURE_MODE_AUTOMATIC = 0x80
    ## passive mode
    _MEASURE_MODE_PASSIVE = 0x00
    ## passive mode configure registers
    _CMD_DISTANCE_MEASURE = 0x01
    ## Ranging from 500
    _MEASURE_RANG_500 = 0x20
    ## Ranging from 300
    _MEASURE_RANG_300 = 0x10
    ## Ranging from 150
    _MEASURE_RANG_150 = 0x00

    SLAVEADDR_INDEX = 0
    PID_INDEX = 1
    VERSION_INDEX = 2
    DIST_H_INDEX = 3
    DIST_L_INDEX = 4
    TEMP_H_INDEX = 5
    TEMP_L_INDEX = 6
    CFG_INDEX = 7
    CMD_INDEX = 8
    REG_NUM = 9
    txbuf = [0]

    def __init__(self, bus):
        self.i2cbus = smbus.SMBus(bus)

    def set_mode_range(self, range, mode):
        '''!
      @brief    set dc motor encoder reduction ratio
      @param range: Measured distance
      @n            _MEASURE_RANG_500             #Ranging from 500
      @n            _MEASURE_RANG_300             #Ranging from 300
      @n            _MEASURE_RANG_150             #Ranging from 150
      @param mode: Set mode
      @n            _MEASURE_MODE_AUTOMATIC       #automatic mode
      @n            _MEASURE_MODE_PASSIVE         #passive mode
    '''
        self.txbuf = [range | mode]
        self.write_reg(self.CFG_INDEX, self.txbuf)

    def measurement_start(self):
        '''!
      @brief    Passive mode ranging command
    '''
        self.txbuf = [self._CMD_DISTANCE_MEASURE]
        self.write_reg(self.CMD_INDEX, self.txbuf)

    def get_temperature(self):
        '''!
      @brief    get Temperature
      @return   Temperature
    '''
        rslt = self.read_reg(self.TEMP_H_INDEX, 2)
        if rslt == -1:
            return 25.0
        return (float)(((rslt[0] << 8) + rslt[1]) / 10)

    def get_distance(self):
        '''!
      @brief    get distance
      @return   Distance
    '''
        temp = 0.0
        rslt = self.read_reg(self.DIST_H_INDEX, 2)
        if rslt == -1:
            return -1
        if ((rslt[0] << 8) + rslt[1]) < 32768:
            return ((rslt[0] << 8) + rslt[1])
        else:
            return (((rslt[0] << 8) + rslt[1]) - 65536)

    def modify_device_number(self, Address):
        '''!
      @brief    Modify i2c device number
      @param Address: i2c device number 1-127
    '''
        self.txbuf = [Address]
        self.write_reg(self.SLAVEADDR_INDEX, self.txbuf)

    def get_device_number(self):
        '''!
      @brief    read i2c device number
      @return   i2c device number
    '''
        rslt = self.read_reg(self.SLAVEADDR_INDEX, 1)
        return rslt[0]

    @property
    def MEASURE_MODE_AUTOMATIC(self):
        return self._MEASURE_MODE_AUTOMATIC

    @property
    def MEASURE_RANG_150(self):
        return self._MEASURE_RANG_150


class DFRobot_URM09_IIC(DFRobot_URM09):
    def __init__(self, bus, addr):
        self.__addr = addr
        super(DFRobot_URM09_IIC, self).__init__(bus)

    def write_reg(self, reg, data):
        while 1:
            try:
                self.i2cbus.write_i2c_block_data(self.__addr, reg, data)
                return
            except:
                print("please check connect!")
                time.sleep(1)

    def read_reg(self, reg, len):
        try:
            rslt = self.i2cbus.read_i2c_block_data(self.__addr, reg, len)
        except:
            rslt = -1
        return rslt

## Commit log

2020-12-30 Added arduino code with libs and python code
2021-01-01 added input test file. SWitch to L298N for controlling drive motors
2021-01-04 before switch to SerialTransfer lib
2021-01-05 fixed/improved communication with arduino, added direction data
    [mower_controller.py, mower_motor_control.ino]
2021-03-08 Added code for new mow motor drive, commented odometer code out
2021-03-13 Cleanup and added relay usage
2021-06-20 added initial area recognition code
    [pyvenv.cfg]
2021-06-21 Update arduino script
2021-07-05 Renamed area_regognition to image_classification, added ai enabled mower controller
    [pyvenv.cfg]
2021-07-16 Added image classification thread to controller
2021-07-16 Fixed errors in mower controller, added better, larger tflite model
    [mower_controller_ai.py]
2022-04-10 added DFRobot_URM09.py, models for parts
    [MaeherScheibe.scad, MaeherScheibe.stl, MaeherVorderrad.scad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]

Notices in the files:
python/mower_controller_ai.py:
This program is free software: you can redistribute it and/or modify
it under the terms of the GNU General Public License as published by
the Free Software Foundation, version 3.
